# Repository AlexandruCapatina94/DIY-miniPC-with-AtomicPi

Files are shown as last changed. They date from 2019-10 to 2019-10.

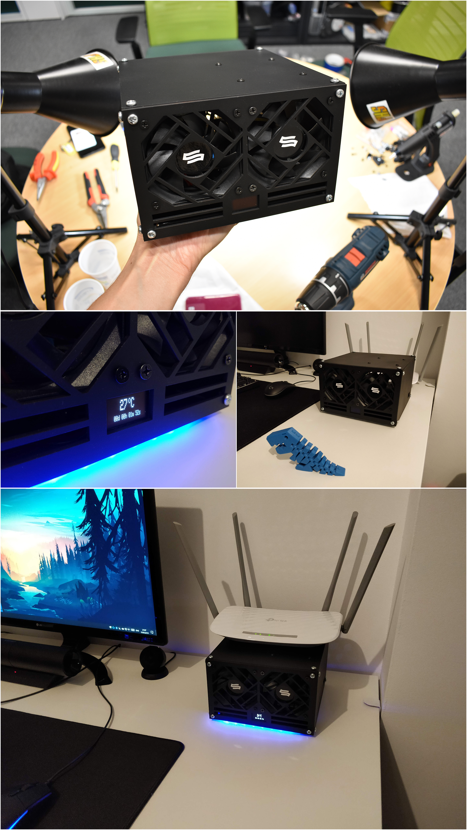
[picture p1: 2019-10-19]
Photos/Colaj.jpg

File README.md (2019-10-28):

# DIY-miniPC-with-AtomicPi



This repository includes the 3d models, code, list of components and pictures in order to build a miniPC with the AtomicPi SBC.

List of components used by me:

- AtomicPi

- MeanWell PSU (5V and 12V), dimensions: 127 * 76 * 42mm (L * W * H)

- 3D modelled case which I laser-cut from 2.5mm MDF

- the drive from a 1TB WD my Passport (2.5" drive)

- 2 x 80mm silent fans

- USB3 dongle for additional ports

- mini OLED screen

- temperature sensor, light sensor

- 12V LED strip

- Arduino Nano for controlling the OLED screen, LEDs and measure temperature and light

- transistors, rezistors etc.

- DIY USB mod for the camera port

- DIY connector to power the AtomicPi

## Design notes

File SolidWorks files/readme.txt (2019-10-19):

This folder contains all the 3D models that I made for this miniPC. The FAN design is from GrabCAD.

The version of SolidWorks used is 2019.

This is just for personal use and is NOT intended for commercial use.

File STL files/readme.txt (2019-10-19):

This folder contains all the STL files if you want to print the case along with the spacers for the
AtomicPi and the PSU and the fixtures for the walls.

Please bare in mind that if you use the same fans as I did, you will need to modify the 2 fixtures that
go in the top front corners because there is not enough space. I used some sandpaper to trim them.

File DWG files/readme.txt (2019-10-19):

This folder contains DWG and DXF files for the case.

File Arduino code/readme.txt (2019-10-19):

This folder contains the Arduino code to turn on the FANs and LEDs on certain environmental conditions.

The LEDs will turn on when there is very low light in your room, in order to make ambient lighting
The FANs will turn on when the temperature of the thermistor (I put it between the fins of the AtomicPi heatsink) is above 35 Celsius.

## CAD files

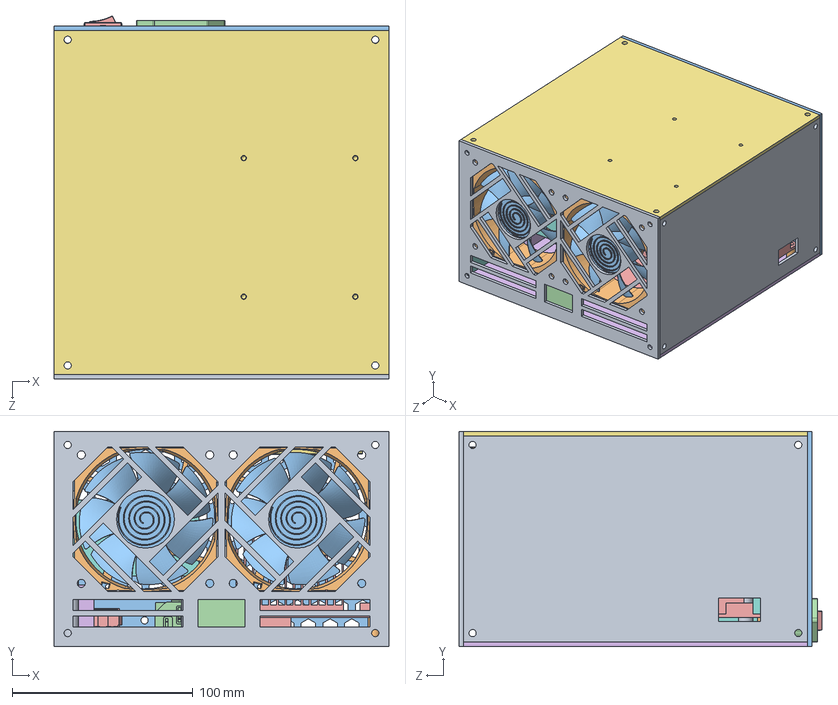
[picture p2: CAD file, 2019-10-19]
SolidWorks files/NAS_Assembly.SLDASM
185.0 x 119.1 x 200.6 mm
FAN Shield
Outer ring x 2
FAn 1 x 2
OLED screen
AtomicPi
USB_HUB
2.5 HDD1
PSU_new
PSU Lifters x 4
API Lifters x 4
Back plate
AC Power Socket
On off switch
Bottom plate
Left plate

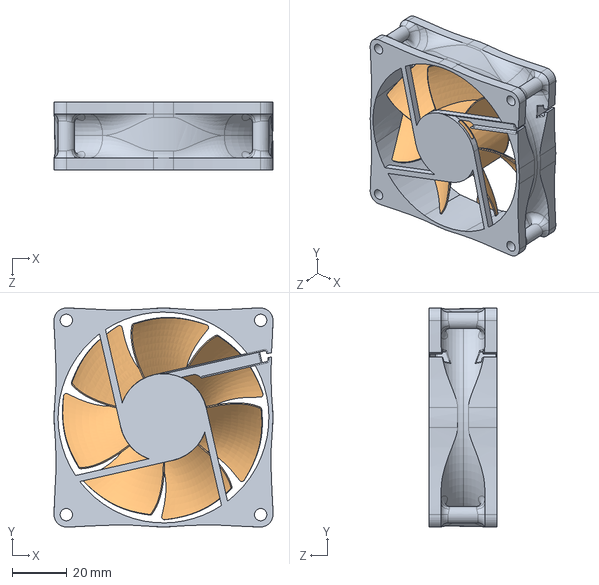
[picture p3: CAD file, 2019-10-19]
SolidWorks files/Pc 80mm fan.SLDASM
80.0 x 80.0 x 25.0 mm
Outer ring
FAn 1

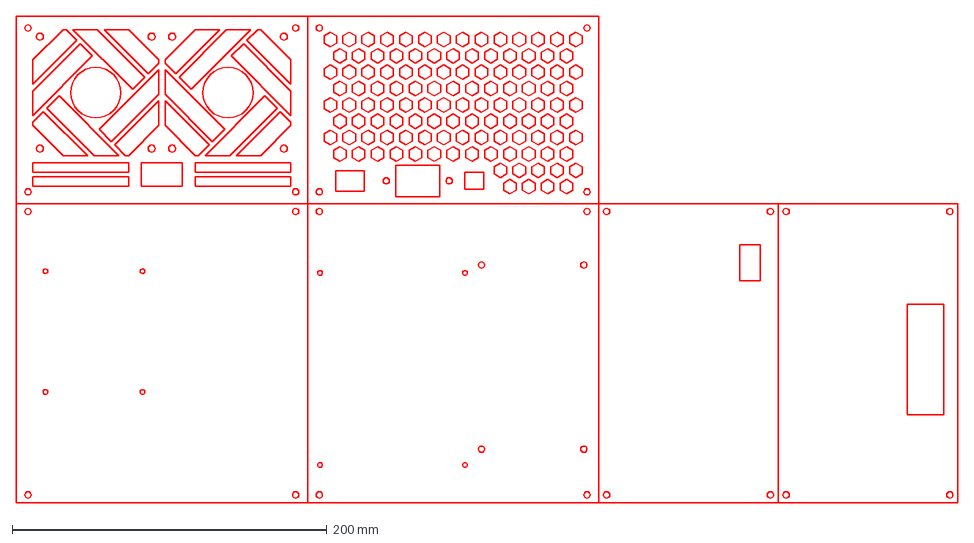
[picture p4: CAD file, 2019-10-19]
DWG files/NAS_90x60cm.DXF
598.0 x 309.0 mm

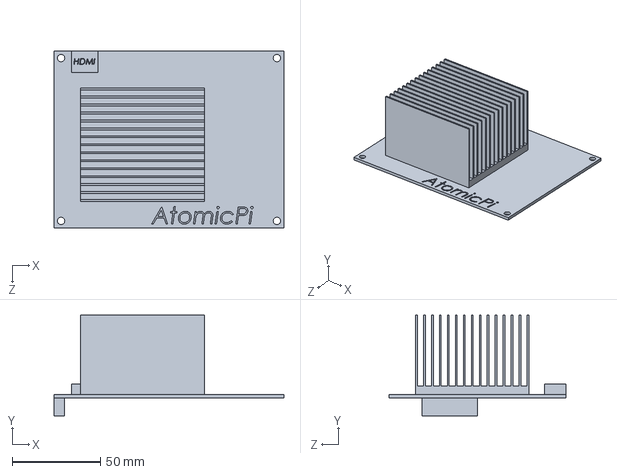
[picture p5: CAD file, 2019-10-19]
SolidWorks files/AtomicPi.SLDPRT
130.0 x 57.0 x 100.0 mm

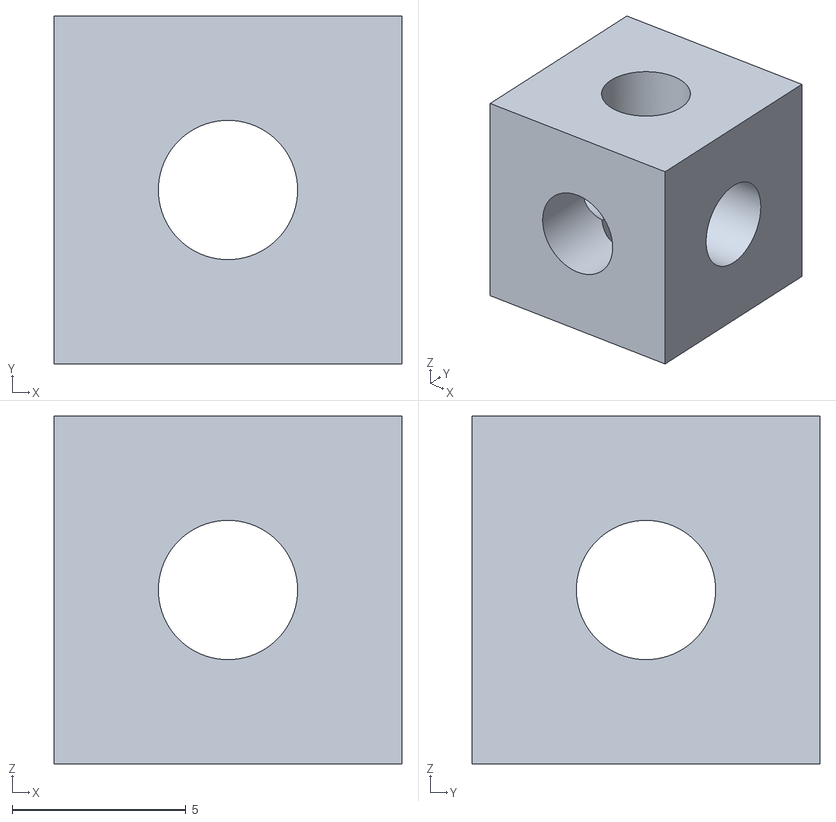
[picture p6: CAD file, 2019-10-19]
STL files/Fixture.STL
10.0 x 10.0 x 10.0

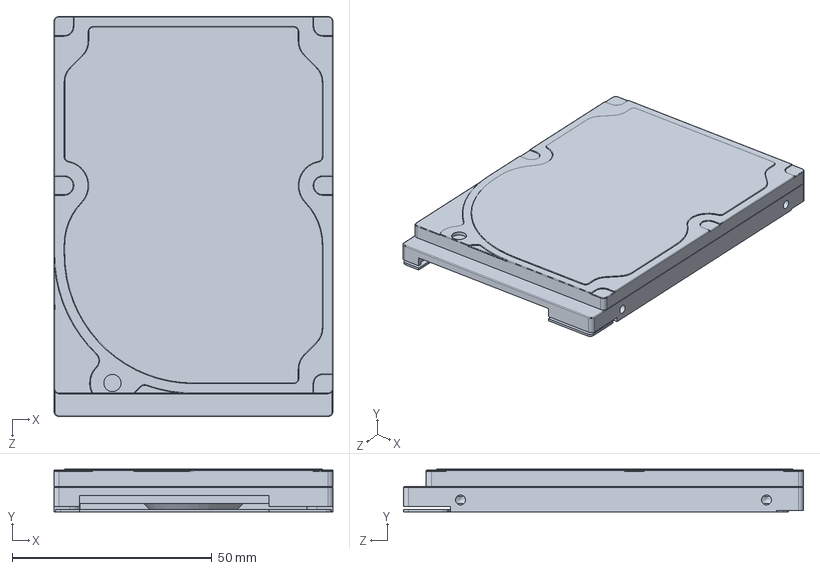
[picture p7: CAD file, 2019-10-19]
SolidWorks files/2.5 HDD1.SLDPRT
69.8 x 10.7 x 100.2 mm

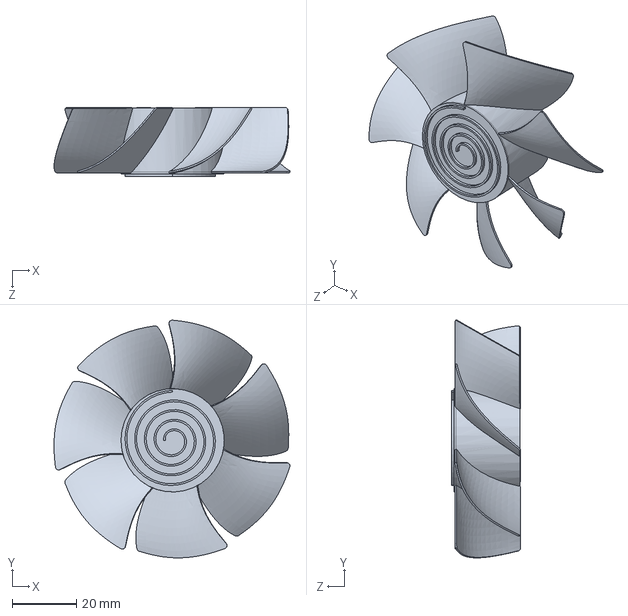
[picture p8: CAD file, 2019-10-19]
SolidWorks files/FAn 1.SLDPRT
73.4 x 73.9 x 21.5 mm

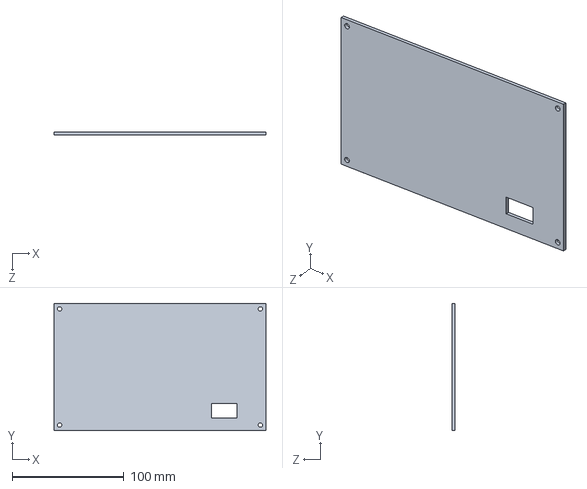
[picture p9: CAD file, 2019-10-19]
SolidWorks files/Right plate.SLDPRT
190.0 x 114.0 x 2.50 mm

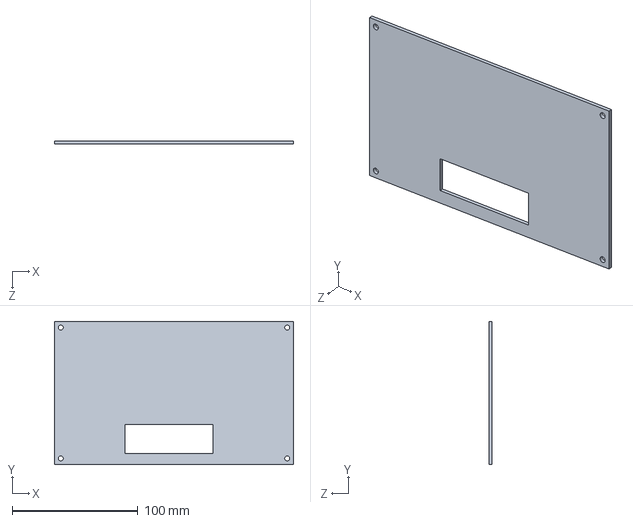
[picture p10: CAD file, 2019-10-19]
SolidWorks files/Left plate.SLDPRT
190.0 x 114.0 x 2.50 mm

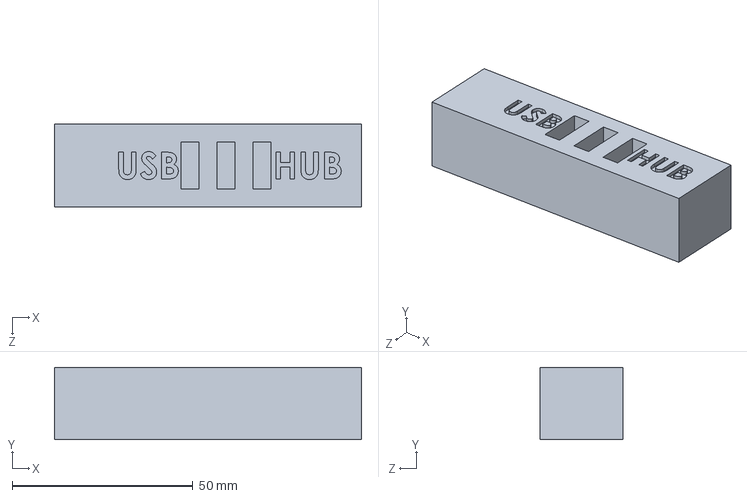
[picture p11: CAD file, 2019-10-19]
SolidWorks files/USB_HUB.SLDPRT
85.0 x 20.0 x 23.0 mm

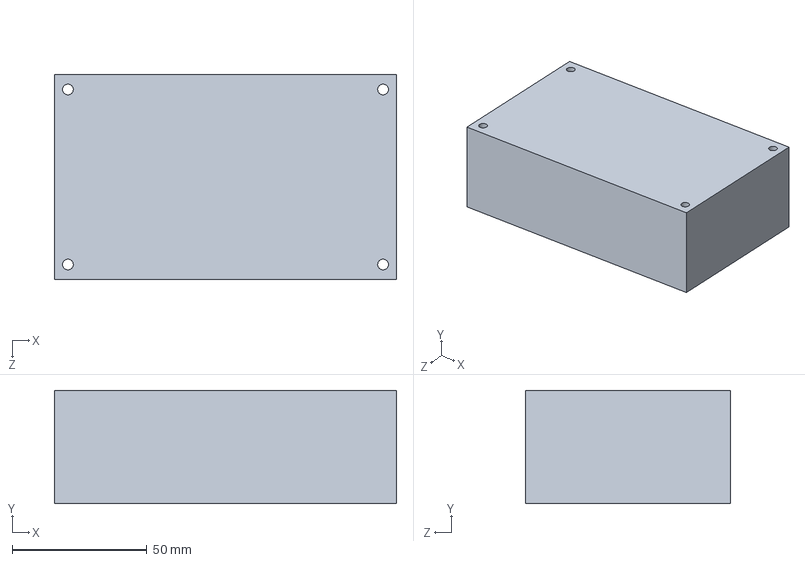
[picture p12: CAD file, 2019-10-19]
SolidWorks files/PSU_new.SLDPRT
127.0 x 42.0 x 76.0 mm

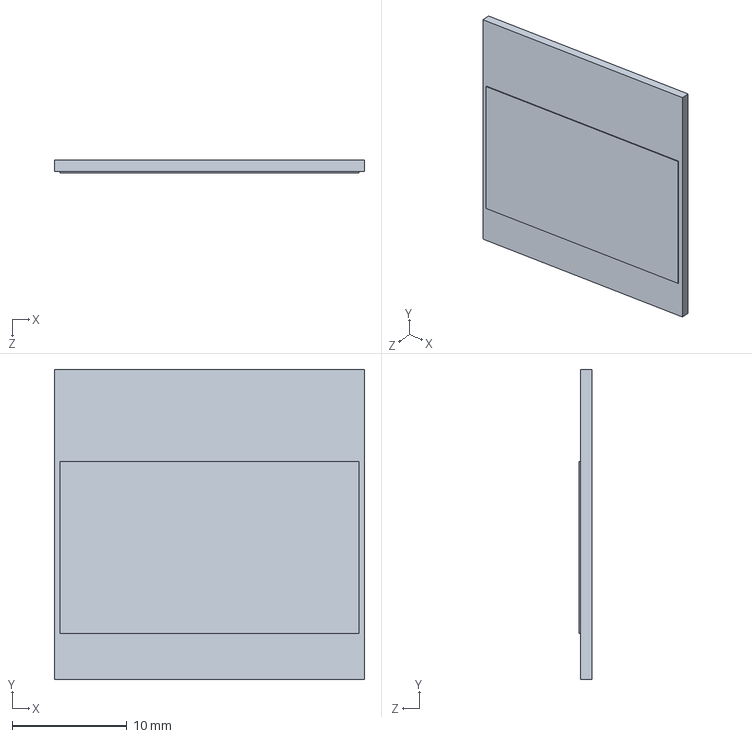
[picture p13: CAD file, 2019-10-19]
SolidWorks files/OLED screen.SLDPRT
27.0 x 27.0 x 1.10 mm

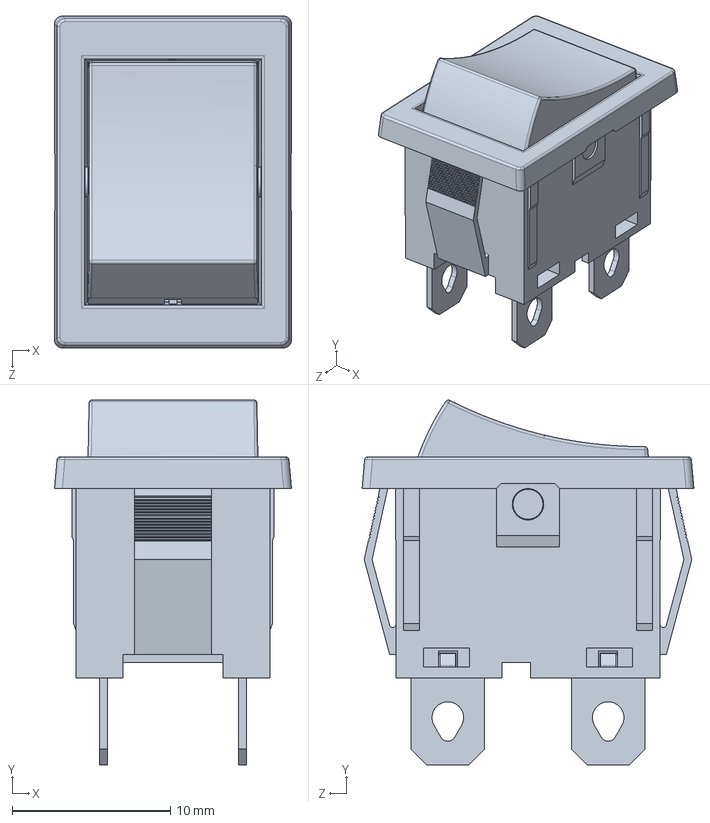
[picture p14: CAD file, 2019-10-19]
SolidWorks files/On off switch.SLDPRT
15.0 x 23.1 x 21.0 mm

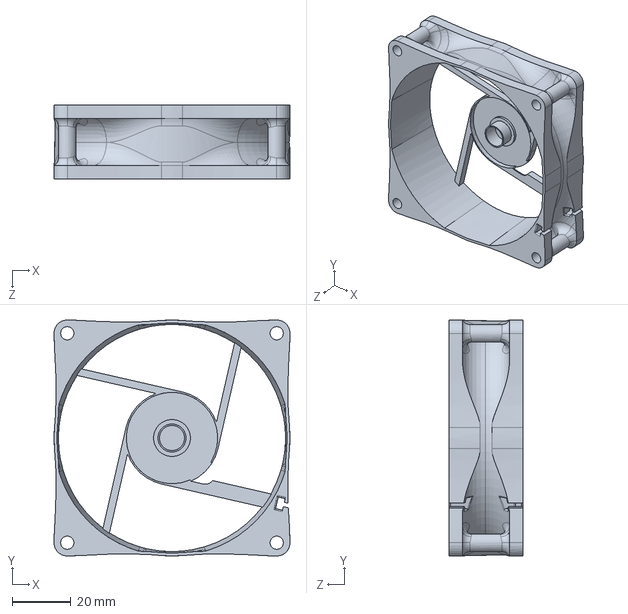
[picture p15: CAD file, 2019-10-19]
SolidWorks files/Outer ring.SLDPRT
80.0 x 80.0 x 25.0 mm

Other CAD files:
SolidWorks files/PSU Lifters.SLDPRT
SolidWorks files/Top plate.SLDPRT
SolidWorks files/API Lifters.SLDPRT
SolidWorks files/Bottom plate.SLDPRT
DWG files/NAS_90x60cm.DWG
STL files/API Lifters.STL
STL files/Back plate.STL
STL files/Bottom plate.STL
STL files/FAN Shield.STL
STL files/Left plate.STL
STL files/PSU Lifters.STL
STL files/Right plate.STL
STL files/Top plate.STL
SolidWorks files/AC Power Socket.SLDPRT
SolidWorks files/Back plate.SLDPRT
SolidWorks files/FAN Shield.SLDPRT

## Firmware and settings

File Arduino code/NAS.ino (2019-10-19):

#include <SPI.h>
#include <Wire.h>
#include <Adafruit_GFX.h>
#include <Adafruit_SSD1306.h>


//BEGIN OLED CONFIG
#define SCREEN_WIDTH 128 // OLED display width, in pixels
#define SCREEN_HEIGHT 32 // OLED display height, in pixels

// Declaration for an SSD1306 display connected to I2C (SDA, SCL pins)
#define OLED_RESET     4 // Reset pin # (or -1 if sharing Arduino reset pin)
Adafruit_SSD1306 display(SCREEN_WIDTH, SCREEN_HEIGHT, &Wire, OLED_RESET);
//END OLED CONFIG

//BEGIN TIMER CONFIG
long Day = 0;
int Hour = 0;
int Minute = 0;
int Second = 0;
int HighMillis = 0;
int Rollover = 0;
//END TIMER CONFIG

//BEGIN SENSOR CONFIG
int LED = 5;             //LED output pin
int FAN = 9;             //FAN output pin
int flagFAN = 0;
int flagLED = 0;
double Temp = 0;
int t = 0;
//END SENSOR CONFIG

void setup() {
  // put your setup code here, to run once:
  digitalWrite(FAN, LOW);

  Serial.begin(9600);
  // SSD1306_SWITCHCAPVCC = generate display voltage from 3.3V internally
  if (!display.begin(SSD1306_SWITCHCAPVCC, 0x3C)) { // Address 0x3C for 128x32
    Serial.println(F("SSD1306 allocation failed"));
    for (;;); // Don't proceed, loop forever
  }
  // Clear the buffer
  display.clearDisplay();
  // Show the display buffer on the screen. You MUST call display() after
  // drawing commands to make them visible on screen!
  display.display();
}

void loop() {

  int y = analogRead(A3);    //read light sensor
  //Serial.println(y);

  if (y > 700 && flagLED == 0)
  {
    analogWrite(LED, 100);
    flagLED = 1;
  }
  if (y < 500 && flagLED == 1)
  {
    flagLED = 0;
    digitalWrite(LED, LOW);
  }
  
  temp();      //read temp and convert to Celsius

  // display temp
  display.setTextSize(2);
  display.setTextColor(WHITE);
  display.setCursor(40  , 3);
  display.print(t);
  display.drawCircle(70, 6, 3, WHITE);
  display.print(" C");

  // start FAN
  if (t >= 35 && flagFAN == 0)     //threshold temperature to start the fans at ~70%
  {
    analogWrite(FAN, 200);
    flagFAN = 1;
  }

  if (t >= 50 && flagFAN == 1)     //threshold temperature to start the fans at max speed
  {
    digitalWrite(FAN, HIGH);
  }

  if (t <= 30 && flagFAN == 1)     //stop the fans when temperature is 5 degrees below threshold
  {
    flagFAN = 0;
    digitalWrite(FAN, LOW);
  }


  // display timer
  uptime(); //Runs the uptime script located below the main loop and reenters the main loop
  print_Uptime();


  // update display with all of the above graphics
  display.display();
  display.clearDisplay();

  delay(100);  //update screen every 100ms
}


void temp()
{
  int Vo = analogRead(A2);
  Temp = log(((10240000 / Vo) - 10000));
  Temp = 1 / (0.001129148 + (0.000234125 + (0.0000000876741 * Temp * Temp )) * Temp );
  Temp = Temp - 273.15;
  t = Temp;
}

void uptime() {
  //** Making Note of an expected rollover *****//
  if (millis() >= 3000000000) {
    HighMillis = 1;

  }
  //** Making note of actual rollover **//
  if (millis() <= 100000 && HighMillis == 1) {
    Rollover++;
    HighMillis = 0;
  }

  long secsUp = millis() / 1000;

  Second = secsUp % 60;

  Minute = (secsUp / 60) % 60;

  Hour = (secsUp / (60 * 60)) % 24;

  Day = (Rollover * 50) + (secsUp / (60 * 60.0 * 24)); //First portion takes care of a rollover [around 50 days]
}

void print_Uptime()
{
  display.setTextSize(1);
  display.setTextColor(WHITE);
  display.setCursor(20, 23);
  if (Day < 10)
    display.print("0");
  display.print(Day);
  display.print("d ");
  if (Hour < 10)
    display.print("0");
  display.print(Hour);
  display.print("h ");
  if (Minute < 10)
    display.print("0");
  display.print(Minute);
  display.print("m ");
  if (Second < 10)
    display.print("0");
  display.print(Second);
  display.print("s");

}
